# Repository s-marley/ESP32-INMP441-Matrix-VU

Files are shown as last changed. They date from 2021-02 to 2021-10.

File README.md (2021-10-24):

# ESP32-INMP441-Matrix-VU
**IMPORTANT: For now, the code will only work with ESP32 core 1.0.6, and is unreliable on 2.0.0. I'm thinking this is a FastLED issue, but I might be wrong on that! Use the boards manager to revert to 1.0.6 in order to compile and upload.**

This is the repository for a 3D-printed, (optionally) battery-powered, WS2812B LED matrix that produces pretty patterns using audio input from an INMP441 digital microphone and running on an ESP32. Watch the explanatory video at the YouTube link below:

Youtube video of VU meter in action (https://www.youtube.com/watch?v=9PEjvFkdpIE)

## Hardware
At a minimum, you will need:
* A 3D printer to produce the case, STLs are available.
* An ESP32 dev board, the exact type doesn't matter.
* An 8x8 (80x80 mm) or 16x16 (160x160 mm) WS2812B LED matrix.
  * My code should work with any matrix providing the width is 8 or a multiple of 16. The height isn't important. If you're using WLED, you can have whatever size you like!
  * The data input for my matrix is at the bottom-left, and is wired in a horizontal zig-zag pattern.
* An INMP441 I2S microphone.
* A power switch
* A DC input socket and 5V power supply if you are not powering from a battery.
* The usual electronics tools and equipment to build it.

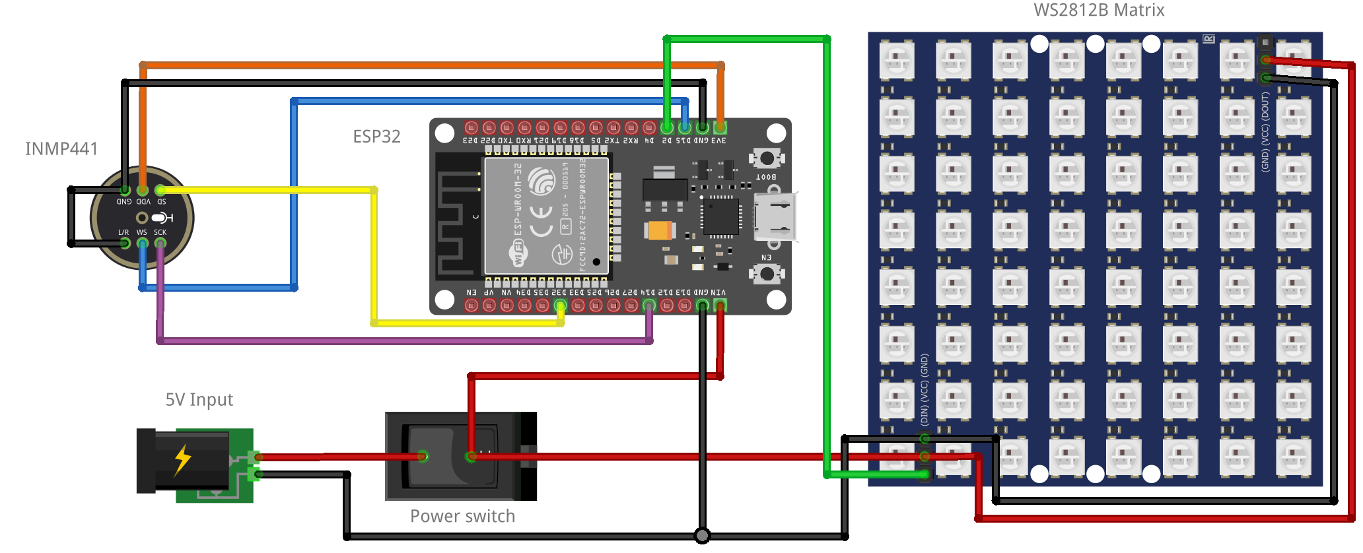
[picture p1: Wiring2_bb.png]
No battery schematic


If you want to battery power your creation, you will also need:
* A LiPo / LiIon battery - exact specs depend on the run time you need and what solution you are using for your charge / boost circuits.
* A charge / boost board to connect to your battery and output 5V for the LEDs.
  * Alternatively you could use seperate modules for these functions, this might be a good idea for the higher power 16x16 matrix.

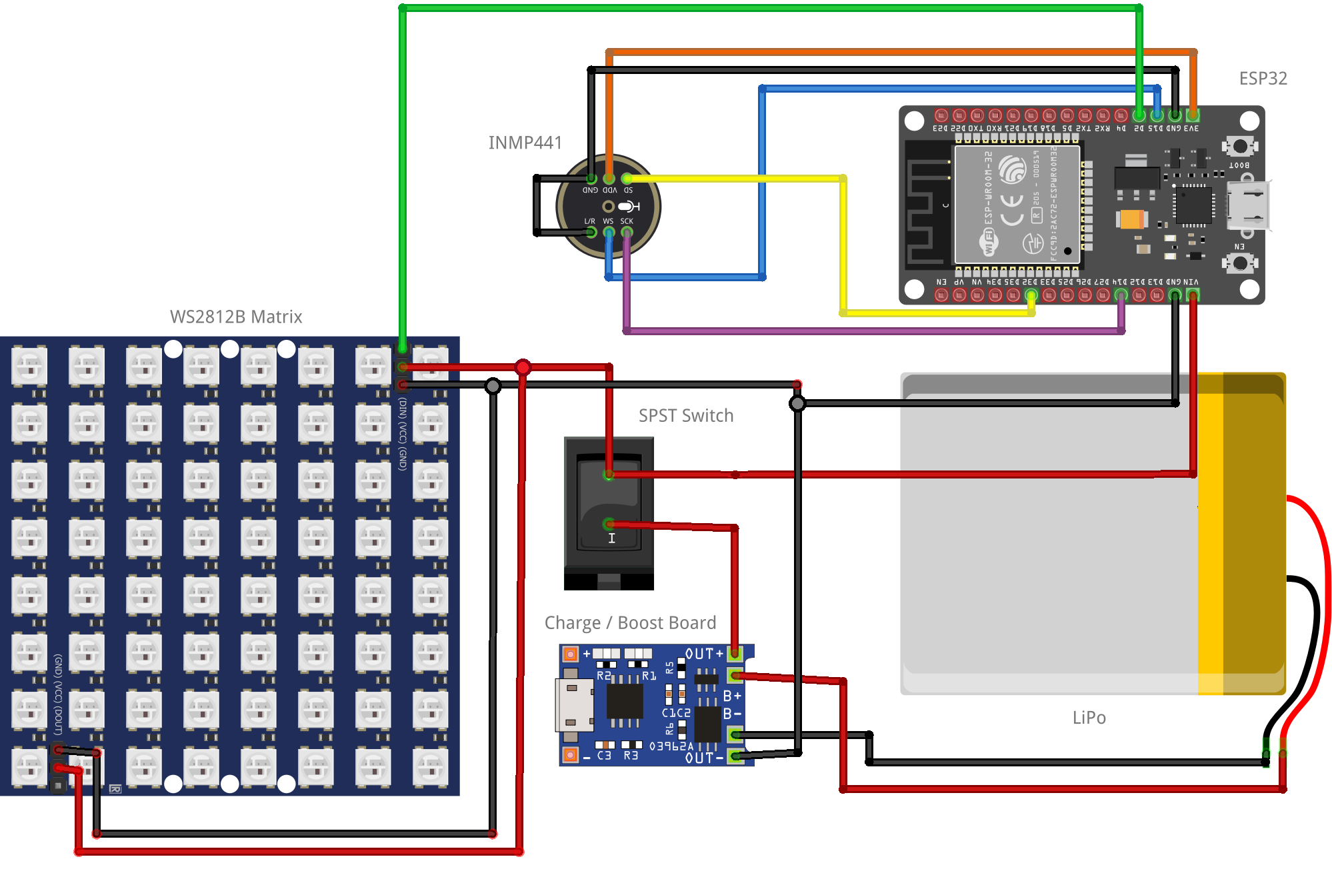
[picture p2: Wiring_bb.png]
Battery schematic


## Software
Regarding software you have two main options, the software given in this repository or [WLED sound reactive fork](https://github.com/atuline/WLED). The hardware connections are the same for either option. There are many advatages of using WLED over this software, it's a much more complete solution with better support for syncing multiple controllers setting up playlists of patterns and customising the patterns that exist. The only realy advantage of my software is that I wanted to write my own patterns and be able to completely customise how things worked. The choice is yours. If you want to use my software, read on...

**Software setup**
1. Download the code, and make sure you have all of the required libraries installed. They are listed at the top of the .ino file.
2. Make sure your matrix is set up correctly in the software for input position, and wiring style. See notes at the top of the .ino file for more details.
3. Change `M_WIDTH` and `M_HEIGHT` to the correct number of LEDs for your matrix.
4. Go into web_server.h and change `ssid`, `password`, `ssid2`, and `password2` to your primary and backup network credentials.
5. Upload the code to your ESP32 and hope for the best!

## Using the matrix
Every time you power the matrix, it will attempt to connect to the primary WiFi network for 5 seconds. If this fails, it will try the secondary credentials for 5 seconds. If this also fails, it will fall back to whatever its previous setting were, but you will be unable to make any changes. I have the secondary credentials set to the hotspot on my phone, so I can use the device outside of my home network.
If it succeeds in connecting to a network, the local IP of the ESP will scroll across the screen. Go to this address in any browser to change the settings. The settings that can be altered are:
* Next pattern - Self explanatory.
* Auto-change pattern - Will cycle through the patterns every so many seconds, defined by...
* Seconds to show each pattern on auto - Values between 1 and 65535 seconds accepted
* Brightness - Be carerful here, at max brightness the larger panels can consume many amps. Make sure your power supply is up to the job!
* Gain - Increases the sensitivity of the microphone to adjust for louder or quieter environoments.
* Squelch - Increasing this value puts a limit on the quietest sounds that will be picked up. Useful for if you have some background noise to remove.
The settings are saved in the EEPROM so they should remain the same across power cycles.

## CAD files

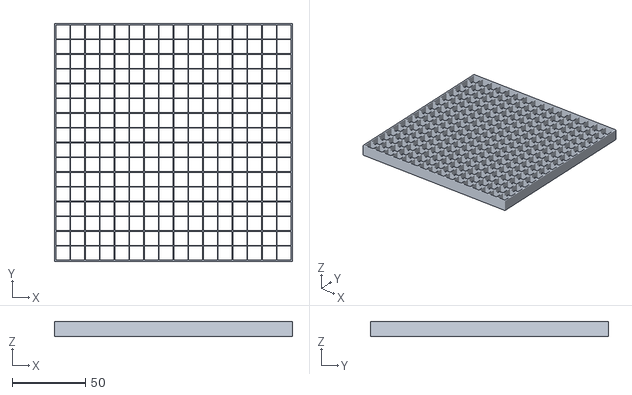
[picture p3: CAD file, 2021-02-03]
3D Models/16x16/Grid.stl
162.0 x 162.0 x 10.00

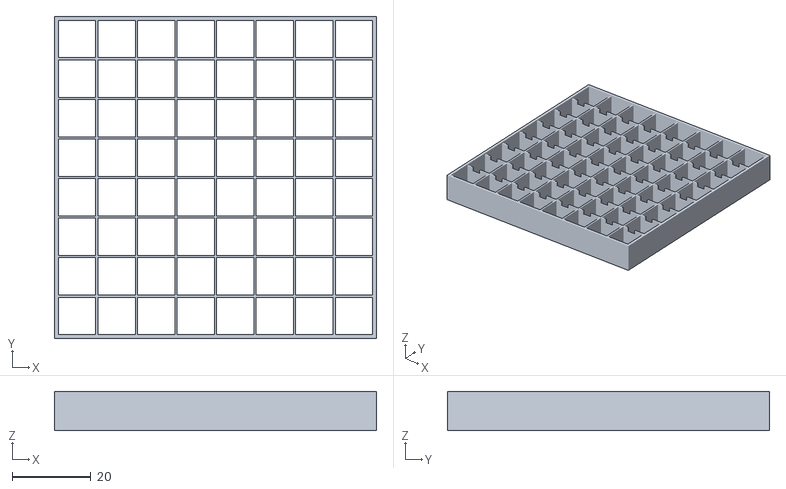
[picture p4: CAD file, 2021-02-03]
3D Models/8x8/Grid.stl
82.0 x 82.0 x 10.00

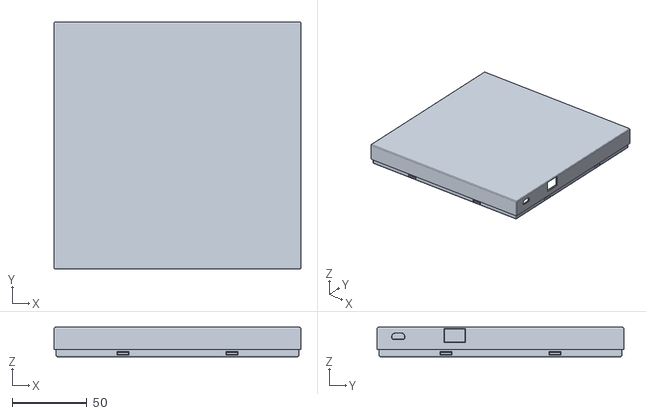
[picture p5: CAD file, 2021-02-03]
3D Models/16x16/Back face.stl
165.2 x 165.2 x 19.8

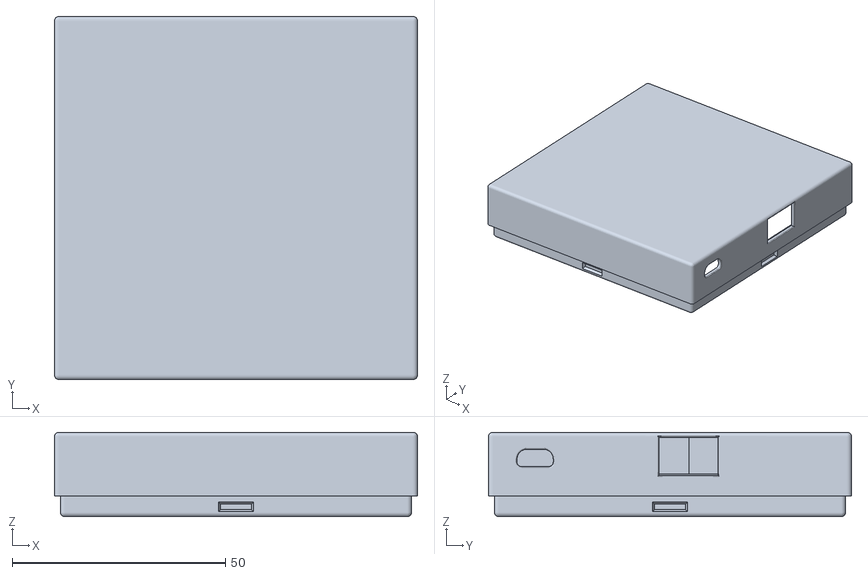
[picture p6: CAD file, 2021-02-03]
3D Models/8x8/Back face.stl
85.2 x 85.2 x 19.8

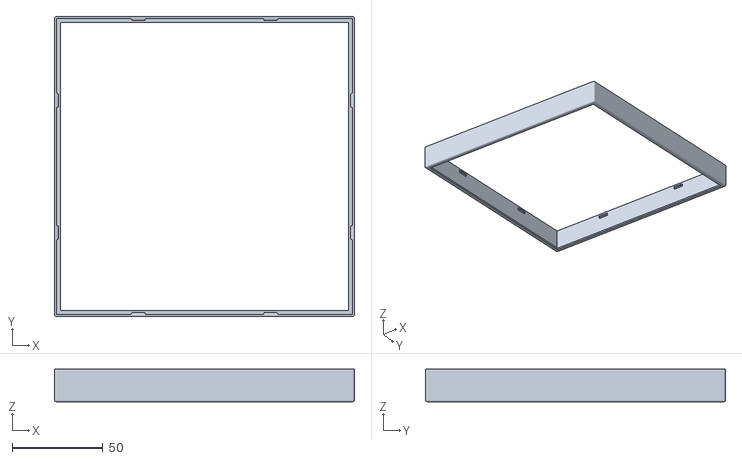
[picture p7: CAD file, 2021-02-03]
3D Models/16x16/Front face.stl
165.2 x 165.2 x 18.0

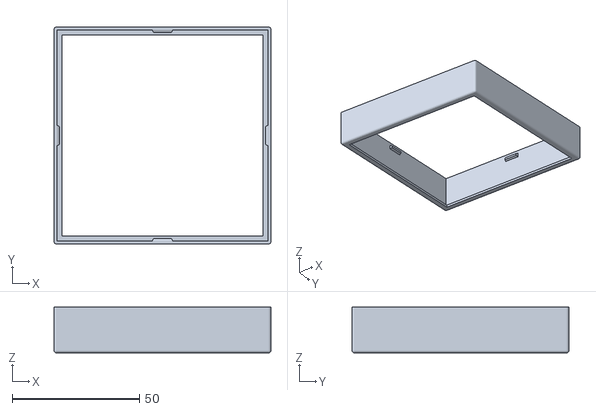
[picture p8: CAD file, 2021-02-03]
3D Models/8x8/Front face.stl
85.2 x 85.2 x 18.0

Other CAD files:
3D Models/16x16/16x16Matrix.f3d
3D Models/8x8/8x8Matrix.f3d

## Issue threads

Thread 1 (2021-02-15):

Pulse without sound

Sle77en, 2021-02-15:
Hi,

I have pulses without a sound. So even with silence. I suspect that the microphone has a bug. What do you think?

Here you can take a look: https://www.dropbox.com/s/tudjnyesxygd2lo/telegram-cloud-document-2-5282922645820541774.mp4

s-marley, 2021-02-15:
That definitely doens't look right. You could try adding a capacitor across the 3V3 and GND lines on the mic, see if there is some electrical interference that is being picked up, but these digital mics are normally pretty good at dealing with that anyway. I'm sure you've already checked that all of your connections are correct? Thats's a nice looking matrix by the way! Try running just  [this code](https://pastebin.com/Ua7s7LYF) without the LEDs, and see if you still pick up those jumps on the serial plotter output.

Sle77en, 2021-02-15:
Hi :) Thanks for your fast answer!
I am now one step closer to the solution. The malfunction only occurs when I operate the matrix with a power supply unit (5V / 10A). There is no disturbance when I operate it via USB via the ESP32.
Do you have a tip for me?

PaoloBassan, 2021-02-15:
hi, i'm trying to build your project but i can't find the <driver / i2s.h> library
can you help me please

s-marley, 2021-02-16:
Sounds like it might be a cheap, noisy power supply! Try the capacitor thing I mentioned and see if that makes a difference. If not, you'll just have to use a higher quality supply unfortunately. Also make sure everything is well grounded as usual.

Sle77en, 2021-02-18:
Yes it was a noisy power supply. Now i have a good one and all works finde :) Thank you very much!

Closed 2021-02-18.

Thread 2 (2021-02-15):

hi, i'm trying to build your project but i can't find the <driver / i2s.h> library

PaoloBassan, 2021-02-15:
hi, i'm trying to build your project but i can't find the <driver / i2s.h> library
can you help me please

_Originally posted by @PaoloBassan in https://github.com/s-marley/ESP32-INMP441-Matrix-VU/issues/1#issuecomment-779302357_

s-marley, 2021-02-16:
If you build it in the Arduino IDE and make sure an ESP32 board is selected as the target the library should be automatically available.

PaoloBassan, 2021-02-16:
great, you helped me a lot and I learned how to solve this and other problems caused by my ignorance on the correct management of libraries and boards.
you are doing a great job :-))

s-marley, 2021-02-17:
No worries, thank you!

Closed 2021-02-17.

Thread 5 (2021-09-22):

'i2s_pop_sample' was not declared in this scope

Cristianistrate, 2021-09-22:
I have this issue,
I read somewhere that "i2s_pop_sample" was deprecated.
I use esp 2.0 board from board manager
Thank you.

BlueAndi, 2022-02-08:
fyi, you find the deprecated info with the proposed replacement in the espressif documentation too: https://docs.espressif.com/projects/esp-idf/en/v3.3.6/api-reference/peripherals/i2s.html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

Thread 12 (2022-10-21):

More as a suggestion: button(s)

Juris3D, 2022-10-21:
Hello! Thank you for your work on projects and sharing! I am wondering, why physical control was removed in this version? Web control is good and all, but - would be convenient still able control without. Was there a technical reason not putting button code from previous analog input version to this project? Thank You!

s-marley, 2022-10-21:
Simply because I didn't need it :) Feel free to add it back in, it would be
easy enough.

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

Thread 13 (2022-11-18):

3D Models - size

nav2go, 2022-11-18:
Looking at the provided 8x8 .stl files, they are 82mm x 82mm. The 8x8 LED boards I could source are more 67x67mm. Also your video shows your 3D grid close to 67mm. What am I missing here?

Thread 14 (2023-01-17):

WIFI connection

jjvelar, 2023-01-17:
Hi,
Great design and great tutorial. Thanks for sharing.
I installed your software and everything went OK, but after a couple of days it is not able to connect to the WIFI, neither first one, nor the second one.
Log shows it tried to connect to first wifi network, then tried unsuccesfully the second one, and as there was no success either, IP is 0.0.0.0
I tried another ESP32 and after loading the same firmware I had the same issue, so it looks it is not related to the hardware.
I guess most evitent cause is an issue with my WIFI network but I have many other devices connected without a problem.
The only thing I have changed in the INO file is autoChangePatterns boolean variable to true.
Any advice?
Thanks and best regards,

José

jjvelar, 2023-01-17:
Solved. It was my router.

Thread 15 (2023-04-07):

PSA:  Even as of today, SP32 core 1.0.6 is required for this code - Symptoms of newer core versions include what appears to be a hardware fault in the INMP441 mic.

dustinsterk, 2023-04-07:
I failed to see the below notice and spent hours troubleshooting what I assumed was a bad INMP441 mic or faulty wiring/soldering.  The symptoms included the levels/visuals bouncing whenever I touched the wire but would not change when speaking close to the mic.  It turns out my issue was software only, and I just needed to downgrade the ESP32 core to 1.0.6 and magically everything worked perfectly.

**IMPORTANT: For now, the code will only work with ESP32 core 1.0.6, and is unreliable on 2.0.0. I'm thinking this is a FastLED issue, but I might be wrong on that! Use the boards manager to revert to 1.0.6 in order to compile and upload.**

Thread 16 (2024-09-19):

The updated version of the VU meter code prepared according to the current libraries.

aGGreSSiv, 2024-09-19:
[INMP441Matrix_RotaryDecoderWithLed2_Test5.zip](https://github.com/user-attachments/files/17057122/INMP441Matrix_RotaryDecoderWithLed2_Test5.zip)

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

[VuMeterPCB.zip](https://github.com/user-attachments/files/17057178/VuMeterPCB.zip)

Hello, the last version that worked was the ESP32 1.6.0 library; it stopped working when we upgraded to higher versions. You can see the information about the current versions in the screenshots I’ve attached. Additionally, since WiFi is not useful for me, I’m running it with a rotary encoder. I prepared a PCB for this, and I'm using it without any issues. To understand which selection I’m changing on the rotary encoder, I also defined one more WS2812 and placed it next to the encoder. I'm sharing this in case it might be helpful to someone.

Pin 23 and pin 19 on the PCB are connected to a matrix panel and one WS2812, respectively. You can understand which one is connected to which in the code.

best regards

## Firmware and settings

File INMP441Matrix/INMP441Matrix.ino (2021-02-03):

/*
 * Web enabled FFT VU meter for a matrix, ESP32 and INMP441 digital mic.
 * The matrix width MUST be either 8 or a multiple of 16 but the height can
 * be any value. E.g. 8x8, 16x16, 8x10, 32x9 etc.
 * 
 * We are using the LEDMatrx library for easy setup of a matrix with various
 * wiring options. Options are:
 *  HORIZONTAL_ZIGZAG_MATRIX
 *  HORIZONTAL_MATRIX
 *  VERTICAL_ZIGZAG_MATRIX
 *  VERTICAL_MATRIX
 * If your matrix has the first pixel somewhere other than the bottom left
 * (default) then you can reverse the X or Y axis by writing -M_WIDTH and /
 * or -M_HEIGHT in the cLEDMatrix initialisation.
 * 
 * REQUIRED LIBRARIES
 * FastLED            Arduino libraries manager
 * ArduinoFFT         Arduino libraries manager
 * EEPROM             Built in
 * WiFi               Built in
 * AsyncTCP           https://github.com/me-no-dev/ESPAsyncWebServer
 * ESPAsyncWebServer  https://github.com/me-no-dev/AsyncTCP
 * LEDMatrix          https://github.com/AaronLiddiment/LEDMatrix
 * LEDText            https://github.com/AaronLiddiment/LEDText
 * 
 * WIRING
 * LED data     D2 via 470R resistor
 * GND          GND
 * Vin          5V
 * 
 * INMP441
 * VDD          3V3
 * GND          GND
 * L/R          GND
 * WS           D15
 * SCK          D14     
 * SD           D32
 * 
 * REFERENCES
 * Main code      Scott Marley            https://www.youtube.com/c/ScottMarley
 * Web server     Random Nerd Tutorials   https://randomnerdtutorials.com/esp32-web-server-slider-pwm/
 *                                  and   https://randomnerdtutorials.com/esp32-websocket-server-arduino/
 * Audio and mic  Andrew Tuline et al     https://github.com/atuline/WLED
 */

#include "audio_reactive.h"
#include <FastLED.h>
#include <LEDMatrix.h>
#include <LEDText.h>
#include <FontMatrise.h>
#include <EEPROM.h>

#define EEPROM_SIZE 5
#define LED_PIN     2
#define M_WIDTH     16
#define M_HEIGHT    16
#define NUM_LEDS    (M_WIDTH * M_HEIGHT)

#define EEPROM_BRIGHTNESS   0
#define EEPROM_GAIN         1
#define EEPROM_SQUELCH      2
#define EEPROM_PATTERN      3
#define EEPROM_DISPLAY_TIME 4

uint8_t numBands;
uint8_t barWidth;
uint8_t pattern;
uint8_t brightness;
uint16_t displayTime;
bool autoChangePatterns = false;

#include "web_server.h"

cLEDMatrix<M_WIDTH, M_HEIGHT, HORIZONTAL_ZIGZAG_MATRIX> leds;
cLEDText ScrollingMsg;

uint8_t peak[] = {0,0,0,0,0,0,0,0,0,0,0,0,0,0,0,0};
uint8_t prevFFTValue[] = {0,0,0,0,0,0,0,0,0,0,0,0,0,0,0,0};
uint8_t barHeights[] = {0,0,0,0,0,0,0,0,0,0,0,0,0,0,0,0};

// Colors and palettes
DEFINE_GRADIENT_PALETTE( purple_gp ) {
  0,   0, 212, 255,   //blue
255, 179,   0, 255 }; //purple
DEFINE_GRADIENT_PALETTE( outrun_gp ) {
  0, 141,   0, 100,   //purple
127, 255, 192,   0,   //yellow
255,   0,   5, 255 };  //blue
DEFINE_GRADIENT_PALETTE( greenblue_gp ) {
  0,   0, 255,  60,   //green
 64,   0, 236, 255,   //cyan
128,   0,   5, 255,   //blue
192,   0, 236, 255,   //cyan
255,   0, 255,  60 }; //green
DEFINE_GRADIENT_PALETTE( redyellow_gp ) {
  0,   200, 200,  200,   //white
 64,   255, 218,    0,   //yellow
128,   231,   0,    0,   //red
192,   255, 218,    0,   //yellow
255,   200, 200,  200 }; //white
CRGBPalette16 purplePal = purple_gp;
CRGBPalette16 outrunPal = outrun_gp;
CRGBPalette16 greenbluePal = greenblue_gp;
CRGBPalette16 heatPal = redyellow_gp;
uint8_t colorTimer = 0;

void setup() {
  FastLED.addLeds<WS2812B, LED_PIN, GRB>(leds[0], NUM_LEDS);
  Serial.begin(57600);

  setupWebServer();
  setupAudio();

  if (M_WIDTH == 8) numBands = 8;
  else numBands = 16;
  barWidth = M_WIDTH / numBands;
  
  EEPROM.begin(EEPROM_SIZE);
  
  // It should not normally be possible to set the gain to 255
  // If this has happened, the EEPROM has probably never been written to
  // (new board?) so reset the values to something sane.
  if (EEPROM.read(EEPROM_GAIN) == 255) {
    EEPROM.write(EEPROM_BRIGHTNESS, 50);
    EEPROM.write(EEPROM_GAIN, 0);
    EEPROM.write(EEPROM_SQUELCH, 0);
    EEPROM.write(EEPROM_PATTERN, 0);
    EEPROM.write(EEPROM_DISPLAY_TIME, 10);
    EEPROM.commit();
  }

  // Read saved values from EEPROM
  FastLED.setBrightness( EEPROM.read(EEPROM_BRIGHTNESS));
  brightness = FastLED.getBrightness();
  gain = EEPROM.read(EEPROM_GAIN);
  squelch = EEPROM.read(EEPROM_SQUELCH);
  pattern = EEPROM.read(EEPROM_PATTERN);
  displayTime = EEPROM.read(EEPROM_DISPLAY_TIME);

  if (WiFi.status() == WL_CONNECTED) showIP();
}  

void loop() {
  if (pattern != 5) FastLED.clear();
  
  uint8_t divisor = 1;                                                    // If 8 bands, we need to divide things by 2
  if (numBands == 8) divisor = 2;                                         // and average each pair of bands together
  
  for (int i = 0; i < 16; i += divisor) {
    uint8_t fftValue;
    
    if (numBands == 8) fftValue = (fftResult[i] + fftResult[i+1]) / 2;    // Average every two bands if numBands = 8
    else fftValue = fftResult[i];

    fftValue = ((prevFFTValue[i/divisor] * 3) + fftValue) / 4;            // Dirty rolling average between frames to reduce flicker
    barHeights[i/divisor] = fftValue / (255 / M_HEIGHT);                  // Scale bar height
    
    if (barHeights[i/divisor] > peak[i/divisor])                          // Move peak up
      peak[i/divisor] = min(M_HEIGHT, (int)barHeights[i/divisor]);
      
    prevFFTValue[i/divisor] = fftValue;                                   // Save prevFFTValue for averaging later
    
  }

  // Draw the patterns
  for (int band = 0; band < numBands; band++) {
    drawPatterns(band);
  }

  // Decay peak
  EVERY_N_MILLISECONDS(60) {
    for (uint8_t band = 0; band < numBands; band++)
      if (peak[band] > 0) peak[band] -= 1;
  }

  EVERY_N_SECONDS(30) {
    // Save values in EEPROM. Will only be commited if values have changed.
    EEPROM.write(EEPROM_BRIGHTNESS, brightness);
    EEPROM.write(EEPROM_GAIN, gain);
    EEPROM.write(EEPROM_SQUELCH, squelch);
    EEPROM.write(EEPROM_PATTERN, pattern);
    EEPROM.write(EEPROM_DISPLAY_TIME, displayTime);
    EEPROM.commit();
  }
  
  EVERY_N_SECONDS_I(timingObj, displayTime) {
    timingObj.setPeriod(displayTime);
    if (autoChangePatterns) pattern = (pattern + 1) % 6;
  }
  
  FastLED.setBrightness(brightness);
  FastLED.show();

  ws.cleanupClients();
}

void drawPatterns(uint8_t band) {
  
  uint8_t barHeight = barHeights[band];
  
  // Draw bars
  switch (pattern) {
    case 0:
      rainbowBars(band, barHeight);
      break;
    case 1:
      // No bars on this one
      break;
    case 2:
      purpleBars(band, barHeight);
      break;
    case 3:
      centerBars(band, barHeight);
      break;
    case 4:
      changingBars(band, barHeight);
      EVERY_N_MILLISECONDS(10) { colorTimer++; }
      break;
    case 5:
      createWaterfall(band);
      EVERY_N_MILLISECONDS(30) { moveWaterfall(); }
      break;
  }

  // Draw peaks
  switch (pattern) {
    case 0:
      whitePeak(band);
      break;
    case 1:
      outrunPeak(band);
      break;
    case 2:
      whitePeak(band);
      break;
    case 3:
      // No peaks
      break;
    case 4:
      // No peaks
      break;
    case 5:
      // No peaks
      break;
  }
}

void showIP(){
  char strIP[16] = "               ";
  IPAddress ip = WiFi.localIP();
  ip.toString().toCharArray(strIP, 16);
  Serial.println(strIP);
  ScrollingMsg.SetFont(MatriseFontData);
  ScrollingMsg.Init(&leds, leds.Width(), ScrollingMsg.FontHeight() + 1, 0, 0);
  ScrollingMsg.SetText((unsigned char *)strIP, sizeof(strIP) - 1);
  ScrollingMsg.SetTextColrOptions(COLR_RGB | COLR_SINGLE, 0xff, 0xff, 0xff);
  ScrollingMsg.SetScrollDirection(SCROLL_LEFT);
  ScrollingMsg.SetFrameRate(160 / M_WIDTH);       // Faster for larger matrices

  while(ScrollingMsg.UpdateText() == 0) {
    FastLED.show();  
  }
}

//////////// Patterns ////////////

void rainbowBars(uint8_t band, uint8_t barHeight) {
  int xStart = barWidth * band;
  for (int x = xStart; x < xStart + barWidth; x++) {
    for (int y = 0; y <= barHeight; y++) {
      leds(x,y) = CHSV((x / barWidth) * (255 / numBands), 255, 255);
    }
  }
}

void purpleBars(int band, int barHeight) {
  int xStart = barWidth * band;
  for (int x = xStart; x < xStart + barWidth; x++) {
    for (int y = 0; y < barHeight; y++) {
      leds(x,y) = ColorFromPalette(purplePal, y * (255 / barHeight));
    }
  }
}

void changingBars(int band, int barHeight) {
  int xStart = barWidth * band;
  for (int x = xStart; x < xStart + barWidth; x++) {
    for (int y = 0; y < barHeight; y++) {
      leds(x,y) = CHSV(y * (255 / M_HEIGHT) + colorTimer, 255, 255); 
    }
  }
}

void centerBars(int band, int barHeight) {
  int xStart = barWidth * band;
  for (int x = xStart; x < xStart + barWidth; x++) {
    if (barHeight % 2 == 0) barHeight--;
    int yStart = ((M_HEIGHT - barHeight) / 2 );
    for (int y = yStart; y <= (yStart + barHeight); y++) {
      int colorIndex = constrain((y - yStart) * (255 / barHeight), 0, 255);
      leds(x,y) = ColorFromPalette(heatPal, colorIndex);
    }
  }
}

void whitePeak(int band) {
  int xStart = barWidth * band;
  int peakHeight = peak[band];
  for (int x = xStart; x < xStart + barWidth; x++) {
    leds(x,peakHeight) = CRGB::White;
  }
}

void outrunPeak(int band) {
  int xStart = barWidth * band;
  int peakHeight = peak[band];
  for (int x = xStart; x < xStart + barWidth; x++) {
    leds(x,peakHeight) = ColorFromPalette(outrunPal, peakHeight * (255 / M_HEIGHT));
  }
}

void createWaterfall(int band) {
  int xStart = barWidth * band;
  // Draw bottom line
  for (int x = xStart; x < xStart + barWidth; x++) {
    leds(x,0) = CHSV(constrain(map(fftResult[band],0,254,160,0),0,160), 255, 255);
  }
}

void moveWaterfall() {
  // Move screen up starting at 2nd row from top
  for (int y = M_HEIGHT - 2; y >= 0; y--) {
    for (int x = 0; x < M_WIDTH; x++) {
      leds(x,y+1) = leds(x,y);
    }
  }
}

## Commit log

2021-02-03 Added circuit images
2021-02-03 Uploaded 3D models
    [16x16Matrix.f3d, 8x8Matrix.f3d, Back face.stl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]
2021-02-03 Updating circuit diagrams
2021-03-20 Add files via upload
    Added Excel file to calculate bins for fft
    [FFT.xlsx]
2021-10-24 Updated i2s code to work with ESP32 core 1.0.6
    Deprecated call to ```i2s_pop_sample``` replaced with ```i2s_read```. Thanks to @tavdog for the fix. Still seems iffy on ESP core 2.0.0, will need further investigation.
